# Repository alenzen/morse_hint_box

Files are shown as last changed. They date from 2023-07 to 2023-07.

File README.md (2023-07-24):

Morse Code Hint Box
===================

A little puzzle game as a weeding gift to our dear friends.

Two Arduino UNOs are involved: the first is the hint box, it has an e-paper
display to show hints and waits for a code word to be sent as Morse code over a
wire. It has a three pin connector. The second is what our friends get to
program themselves. They need to hook it up to the box and Morse the
code word. As code, by a button, however.

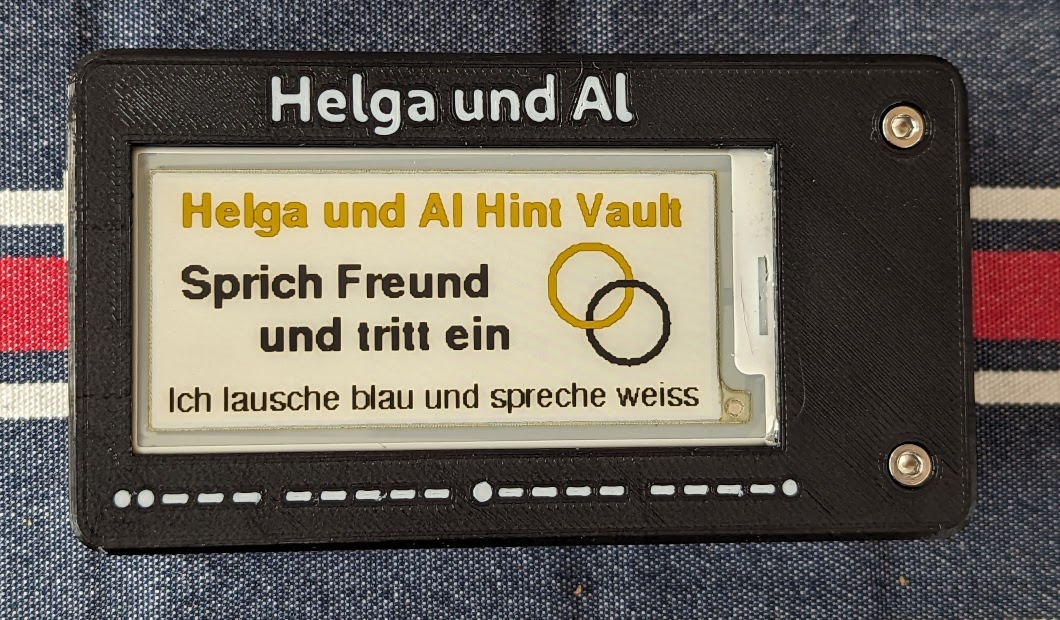
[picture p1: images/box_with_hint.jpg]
Hint box after powering up


Creative Commons BY-NC-SA

Build Instructions
------------------

Material required: Arduino Uno, cables, 2.54 mm 3-pin header (1x female, 1x
male), 2.54 mm 4-pin Dupont connector (1x male, 1x female)
[set with tool](https://www.amazon.de/gp/product/B07QX51F3B/),
[Waveshare E-Paper shield](https://www.waveshare.com/wiki/E-Paper_Shield),
[Waveshare 2.9inch 3-color e-inkdisplay](https://www.waveshare.com/wiki/2.9inch_e-Paper_Module_(C)),
a bit of filament and a 3D printer.

1. Print the housing, update the strings in the slicer files (.3cf). In the
   example, the lower part is a number in Morse code. You need to print with
   supports for the lid, requires a bit of work but are generally easy to
   remove.
2. Mount E-Paper shield to Arduino
3. Solder 3 wires to the shield: 1 to ground, 1 to D3 (this one is important and
   must be on this pin to support hardware interrupts), and 1 to SDA (that one
   doesn't matter too much, you can use another pin as long it's one supporting
   digital output and not colliding with the pins used by the shield). I have
   used solid core cables for this part.
4. Solder the cables to the 2.54 mm male pin header
5. Mount pin header into the holder in the box.
6. Create a connection with three cables, I have used blue (receive), white
   (send), and black (ground). The order on the Dupont header matters:
   ground, empty, white, blue. The empty one is to spare data pin 13, such that
   the builtin LED can be used. This way, I would plug the connector to the
   secondary Arduino into GND, empty on pin 13, and pins 12 and 11.
7. Mount e-paper display into lid, slide cable through hole and display slightly
   into overhang, move fully down and then slide slightly back into far side
   for full hold.
8. Screw lid on body
9. Modify [morse_hint_box.ino](morse_hint_box/morse_hint_box.ino) to your liking
   and upload to box Arduino.
10. Play with [simple_receiver.ino](simple_receiver/simple_receiver.ino) and
    [solution_full_alphabet.ino](solution_full_alphabet/solution_full_alphabet.ino)
    to send and receive.

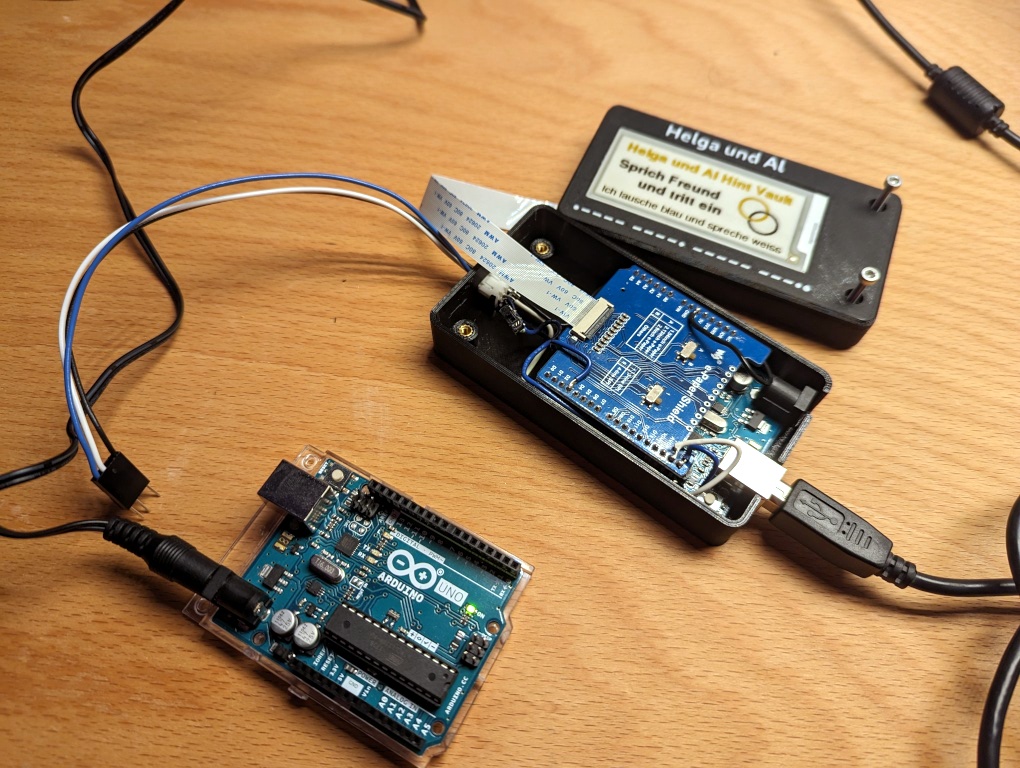
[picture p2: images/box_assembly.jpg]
Hint box assembly


Ignore the switch in the image. I used it to enable switching the input from pin3
to SCL. This way I could also have used I²C for the challenge instead of digital
pins.

Conducting
----------

We did this in-person and the goal of the puzzle is to get another hint to
which person to go next. But obviously this could be tweaked to reveal
anything.

I asked our friends to install the Arduino IDE. They would get the second
Arduino to run their solution. They figured out that it was Morse code rather
quickly. I flashed the second Arduino with [ask_help.ino](ask_help/ask_help.ino).
Then, after plugging in, the Morse parameters and alphabet screens would come up.
The parameters are crucial to be able to properly send.

Then they were equipped with everything necessary and Morse from the bsd-games
package made it (almost too) easy to create the sequence. They initially sent
what was written on the box. Nice try, I nudged them towards the little puzzle
on the start screen. Then it was a matter of typing speed. Overall solving this
took maybe an hour. It was somewhat similar to
[solution_simple.ino](solution_simple/solution_simple.ino).

I'd be really curious for modifications that require sending and receiving. But
the receiver code is a bit more involved and requires some actual programming
(cf. [simple_receiver.ino](simple_receiver/simple_receiver.ino)). I would
consider this in particular if the one supposed to hack the box could do this on
their own time. For the in-person challenge the Morse reading code may be a
little bit too much.

Have fun!

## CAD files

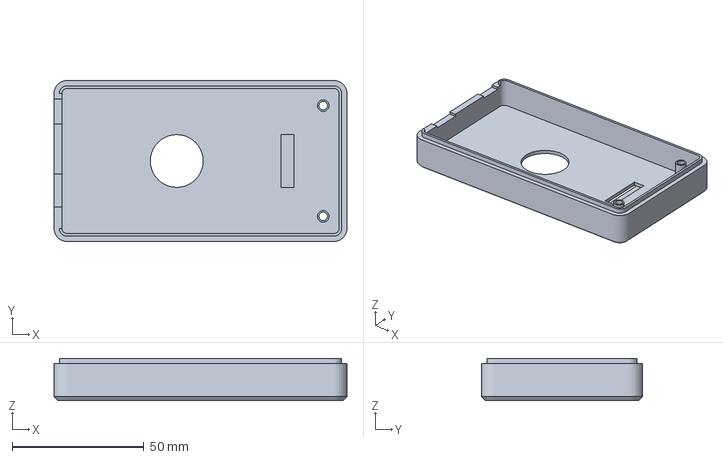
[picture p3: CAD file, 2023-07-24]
models/Arduino_Uno_Case_With_Epaper_Lid_v2.3mf
111.0 x 61.0 x 16.0 mm

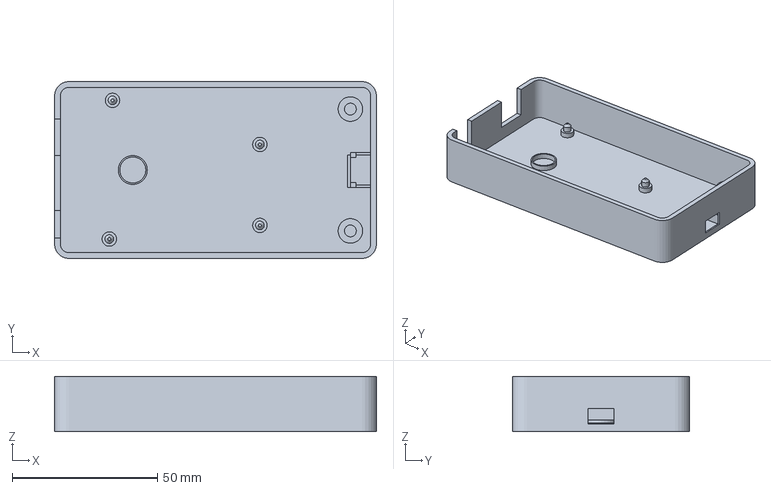
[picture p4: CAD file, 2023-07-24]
models/Arduino_Uno_Case_With_Epaper_Body_v2.3mf
111.0 x 61.0 x 19.0 mm

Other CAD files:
models/Arduino_Uno_Case_With_Epaper_Body_v2.stl
models/Arduino_Uno_Case_With_Epaper_Lid_v2.stl

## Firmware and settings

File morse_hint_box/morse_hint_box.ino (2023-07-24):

// Morse Code Hint Box
// Copyright (C) 2023 Tim Niemueller

// Required libraries: GxEPD2, TimerOne

#include <GxEPD2_BW.h>
#include <GxEPD2_3C.h>
#include <GxEPD2_7C.h>
#include <Fonts/FreeSansBold12pt7b.h>
#include <Fonts/FreeSans9pt7b.h>
#include <TimerOne.h>

// select the display class and display driver class in the following file (new style):
#include "GxEPD2_display_selection_new_style.h"

#define DEG2RAD 0.0174532925

// Morse pins
#define PIN_IN 3
#define PIN_OUT SDA

#define MORSE_CODE_LENGTH 36
const char *morse_code[MORSE_CODE_LENGTH] = {
  // a-z
  ".-", "-...", "-.-.", "-..", ".", "..-.", "--.", "....", "..", ".---", "-.-", ".-..", "--",
  "-.", "---", ".--.", "--.-", ".-.", "...", "-", "..-", "...-", ".--", "-..-", "-.--", "--..",
  // 0-9
  "-----", ".----", "..---", "...--", "....-", ".....", "-....", "--...", "---..", "----."
};

// We accept German and Elvish, no Klingon this time :-)
#define SECRET_WORD_1 "freund"
#define SECRET_WORD_2 "mellon"
#define HELP_WORD "help"

#define INSTRUCTION_SWITCH_INTERVAL 10000

#define TIME_UNIT    (250)
#define DOT          TIME_UNIT
#define DASH         (3*TIME_UNIT)
#define SYMBOL_SPACE TIME_UNIT

#define SEND_LETTER_SPACE  (3*TIME_UNIT - SYMBOL_SPACE)
#define RECV_LETTER_SPACE  (3*TIME_UNIT)
#define SEND_WORD_SPACE    (7 * TIME_UNIT - SEND_LETTER_SPACE)
#define RECV_WORD_SPACE    (7 * TIME_UNIT)
#define RECV_ERASE_TIMEOUT (20 * TIME_UNIT)

#define LETTER_BUFFER_SIZE  8
#define WORD_BUFFER_SIZE   10

#define SYMBOL_DOT  '.'
#define SYMBOL_DASH '-'

// buffer to read strings from progmem
// We need progmem to store strings to reduce SRAM usage.
char progmem_buffer[40];

// Variables for RECEIVING
volatile unsigned long last_low_millis = 0;
volatile unsigned long last_high_millis = 0;
volatile char word_buffer[WORD_BUFFER_SIZE];
volatile char letter_buffer[LETTER_BUFFER_SIZE];
volatile byte letter_buffer_index = 0;
volatile byte word_buffer_index = 0;
volatile bool word_complete = false;

typedef enum {
  INIT,
  START,
  INSTRUCTIONS,
  HINT
} State;
volatile State last_state = INIT;
volatile State state = START;

// Parse buffer of symbols for a single letter
void parse_letter_buffer() {
  for (int i = 0; i < MORSE_CODE_LENGTH; ++i) {
    if (strcmp(morse_code[i], letter_buffer) == 0) {
      if (i < ('z' - 'a')) {
        word_buffer[word_buffer_index] = 'a' + i;
      } else {
        word_buffer[word_buffer_index] = i - ('z' - 'a' + 1) + '0';
      }
      word_buffer_index += 1;
      if (word_buffer_index >= WORD_BUFFER_SIZE) {
        word_complete = true;
      }
    }
  }
  for (int i = 0; i < LETTER_BUFFER_SIZE; ++i) letter_buffer[i] = 0;
  letter_buffer_index = 0;
}

// Remove all data from inflow buffers
void flush_buffers() {
  for (int i = 0; i < LETTER_BUFFER_SIZE; ++i) letter_buffer[i] = 0;
  for (int i = 0; i < WORD_BUFFER_SIZE; ++i) word_buffer[i] = 0;
  letter_buffer_index = 0;
  word_buffer_index = 0;
  word_complete = false;
}

// Interrupt function to read morse code based on signal changes.
void read_morse() {
  if (digitalRead(PIN_IN) == HIGH) {
    digitalWrite(LED_BUILTIN, LOW);
    last_high_millis = millis();
    if ((millis() - last_low_millis) <= 1.1 * DOT) {
      //Serial.println(SYMBOL_DOT);
      letter_buffer[letter_buffer_index] = SYMBOL_DOT;
      letter_buffer_index += 1;
    } else if ((millis() - last_low_millis) <= 1.1 * DASH) {
      //Serial.println(SYMBOL_DASH);
      letter_buffer[letter_buffer_index] = SYMBOL_DASH;
      letter_buffer_index += 1;
    } /* else {
      if (state != HINT) {
        state = INSTRUCTIONS;
      }
    } */
    if (letter_buffer_index >= LETTER_BUFFER_SIZE) {
      // overflow, flush letter buffer
      for (int i = 0; i < LETTER_BUFFER_SIZE; ++i) letter_buffer[i] = 0;
      letter_buffer_index = 0;
    }
  } else {
    digitalWrite(LED_BUILTIN, HIGH);
    last_low_millis = millis();
    unsigned int time_since_high = millis() - last_high_millis;
    if (time_since_high > 0.9 * RECV_LETTER_SPACE) {
      parse_letter_buffer();
    }
    if (time_since_high > 0.9 * RECV_WORD_SPACE && word_buffer_index > 0) {
      word_complete = true;
    }
    if (time_since_high > RECV_ERASE_TIMEOUT) {
      flush_buffers();
    }
  }
}

void write_for(int time_ms) {
  digitalWrite(PIN_OUT, LOW);
  //digitalWrite(LED_BUILTIN, HIGH);
  delay(time_ms);
  digitalWrite(PIN_OUT, HIGH);
  //digitalWrite(LED_BUILTIN, LOW);
  delay(SYMBOL_SPACE);
}

void write_morse(char* message) {
  Serial.print("Sending: ");
  Serial.println(message);
  for (int i = 0; i < strlen(message); ++i) {
    int letter = tolower(message[i]);
    if (letter == ' ') {
      delay(SEND_WORD_SPACE);
    } else if (letter >= 'a' && letter <= 'z') {
      const char* morse_letter = morse_code[letter - 'a'];
      for (int j = 0; j < strlen(morse_letter); ++j) {
        write_for((morse_letter[j] == '.') ? DOT : DASH);
      }
    } else if (letter >= '0' && letter <= '9') {
      const char* morse_letter = morse_code[letter + 26 - '0'];
      for (int j = 0; j < strlen(morse_letter); ++j) {
        write_for((morse_letter[j] == '.') ? DOT : DASH);
      }
    }
    delay(SEND_LETTER_SPACE);
  }
}


const char screenStartTitle[] PROGMEM = "Helga und Al Hint Vault";
const char screenStartRiddle1[] PROGMEM = "Sprich Freund";
const char screenStartRiddle2[] PROGMEM = "und tritt ein";
const char screenStartInstructions[] PROGMEM = "Ich lausche blau und spreche weiss";

void screenStart()
{
  display.setRotation(1);
  display.setFullWindow();
  display.firstPage();
  do
  {
    display.fillScreen(GxEPD_WHITE);
    display.setFont(&FreeSansBold12pt7b);
    display.setTextColor(GxEPD_YELLOW);
    int16_t tbx, tby; uint16_t tbw, tbh;
    strcpy_P(progmem_buffer, screenStartTitle);
    display.getTextBounds(progmem_buffer, 0, 0, &tbx, &tby, &tbw, &tbh);
    // center the bounding box by transposition of the origin:
    uint16_t top_x = ((display.width() - tbw) / 2) - tbx;
    uint16_t y = tbh+2;//((display.height() - tbh) / 2) - tby;
    display.setCursor(top_x, y);
    display.print(progmem_buffer);

    uint16_t radius = 20;
    fillArc2(display.width() - 3.25*radius, tbh+1.75*radius, 0, 120, radius+3, radius+3, 3, GxEPD_YELLOW);
    fillArc2(display.width() - 2.25*radius, tbh+2.75*radius, 0, 120, radius+3, radius+3, 3, GxEPD_BLACK);
    fillArc2(display.width() - 3.25*radius, tbh+1.75*radius, 170, 6, radius+3, radius+3, 3, GxEPD_YELLOW);

    display.setTextColor(GxEPD_BLACK);
    strcpy_P(progmem_buffer, screenStartRiddle1);
    display.getTextBounds(progmem_buffer, 0, 0, &tbx, &tby, &tbw, &tbh);
    uint8_t x = top_x;
    y = tbh+2*radius;
    display.setCursor(x, y);
    display.print(progmem_buffer);

    strcpy_P(progmem_buffer, screenStartRiddle2);
    display.getTextBounds(progmem_buffer, top_x, y, &tbx, &tby, &tbw, &tbh);
    x = top_x + 40;
    y = y + tbh + 10;
    display.setCursor(x, y);
    display.print(progmem_buffer);

    display.setTextColor(GxEPD_BLACK);
    display.setFont(&FreeSans9pt7b);
    strcpy_P(progmem_buffer, screenStartInstructions);
    display.getTextBounds(progmem_buffer, 0, 0, &tbx, &tby, &tbw, &tbh);
    x = ((display.width() - tbw) / 2) - tbx;
    y = (display.height() - tbh - 2) - tby;
    display.setCursor(x, y);
    display.print(progmem_buffer);

  } while (display.nextPage());
}

void displayPrintMorseLetter(uint16_t x, uint16_t y, const char* letter) {
  for (int i = 0; i < strlen(letter); ++i) {
    if (letter[i] == SYMBOL_DOT) {
      //fillArc2(x + i * 8, y - 4, 0, 120, 2, 2, 2, GxEPD_YELLOW);
      display.fillRect(x + i * 8 + 2, y - 10 - 1, 2, 2, GxEPD_YELLOW);
    } else {
      display.fillRect(x + i * 8, y - 10 - 1, 6, 2, GxEPD_YELLOW);
    }
  }
}

void screenMorseAlphabet()
{
  display.setRotation(1);
  display.setFullWindow();
  display.firstPage();
  do
  {
    display.fillScreen(GxEPD_WHITE);
    display.setFont(&FreeSans9pt7b);
    for (int row = 0; row < 9; ++row) {
      for (int col = 0; col < 4; ++col) {
        byte letter_index = row * 4 + col;
        char letter_buffer[] = {
          (letter_index < ('z' - 'a' + 1)) ? ('a' + letter_index) : ('0' + letter_index - ('z' - 'a' + 1)),
          0
        };
        int16_t tbx, tby; uint16_t tbw, tbh;
        display.getTextBounds(letter_buffer, 0, 0, &tbx, &tby, &tbw, &tbh);
        // center the bounding box by transposition of the origin:
        uint16_t x = (col * 74) - tbx + 10;
        uint16_t y = (row * 14) - tby + 1;
        display.setCursor(x, y);
        display.setTextColor(GxEPD_BLACK);
        display.print(letter_buffer);

        display.setCursor(x+20, y);
        display.setTextColor(GxEPD_YELLOW);
        displayPrintMorseLetter(x+20, y + 7, morse_code[letter_index]);
      }
    }
  } while (display.nextPage());
}

const char screenMorseParametersTitle[] PROGMEM = "Morse Parameters";
const char screenMorseSignal[] PROGMEM = "Signal on LOW";
const char screenMorseSymbolLengthDesc[] PROGMEM = "Symbol time:";
const char screenMorseSymbolLength1[] PROGMEM = "DOT 250 ms";
const char screenMorseSymbolLength2[] PROGMEM = "DASH 750 ms";
const char screenMorsePauseLengthDesc[] PROGMEM = "Pause time: ";
const char screenMorsePauseLength1[] PROGMEM = "Symbol 250 ms";
const char screenMorsePauseLength2[] PROGMEM = "Letter 750 ms";
const char screenMorsePauseLength3[] PROGMEM = "Word 1750ms";

void screenMorseParameters()
{
  display.setRotation(1);
  display.setFullWindow();
  display.firstPage();
  do
  {
    display.fillScreen(GxEPD_WHITE);
    display.setFont(&FreeSansBold12pt7b);
    display.setTextColor(GxEPD_YELLOW);
    int16_t tbx, tby; uint16_t tbw, tbh;
    strcpy_P(progmem_buffer, screenMorseParametersTitle);
    display.getTextBounds(progmem_buffer, 0, 0, &tbx, &tby, &tbw, &tbh);
    // center the bounding box by transposition of the origin:
    uint16_t x = ((display.width() - tbw) / 2) - tbx;
    uint16_t y = tbh+2;
    display.setCursor(x, y);
    display.print(progmem_buffer);

    display.setFont(&FreeSans9pt7b);
    display.setTextColor(GxEPD_BLACK);

    x = 16;
    y = 40;
    strcpy_P(progmem_buffer, screenMorseSignal);
    display.setCursor(x, y);
    display.print(progmem_buffer);

    y += 16;
    strcpy_P(progmem_buffer, screenMorseSymbolLengthDesc);
    display.getTextBounds(progmem_buffer, 0, 0, &tbx, &tby, &tbw, &tbh);
    display.setCursor(x, y);
    display.print(progmem_buffer);
    strcpy_P(progmem_buffer, screenMorseSymbolLength1);
    display.setCursor(x + tbw + 4, y);
    display.print(progmem_buffer);
    strcpy_P(progmem_buffer, screenMorseSymbolLength2);
    y += 16;
    display.setCursor(x + tbw + 4, y);
    display.print(progmem_buffer);

    strcpy_P(progmem_buffer, screenMorsePauseLengthDesc);
    y += 18;
    display.setCursor(x, y);
    display.print(progmem_buffer);
    strcpy_P(progmem_buffer, screenMorsePauseLength1);
    display.setCursor(x + tbw + 4, y);
    display.print(progmem_buffer);
    strcpy_P(progmem_buffer, screenMorsePauseLength2);
    y += 16;
    display.setCursor(x + tbw + 4, y);
    display.print(progmem_buffer);
    strcpy_P(progmem_buffer, screenMorsePauseLength3);
    y += 16;
    display.setCursor(x + tbw + 4, y);
    display.print(progmem_buffer);

  } while (display.nextPage());
}

const char screenHintTitle[] PROGMEM = "Geschafft!";
const char screenHintRiddle1[] PROGMEM = "Und nun auf";
const char screenHintRiddle2[] PROGMEM = "zum lieben...";
const char screenHintGroup1[] PROGMEM = "Tob -> Buck -> Tim -> ...";
const char screenHintDots[] PROGMEM = "...";
const char screenHintGroup2[] PROGMEM = "Appel";

void screenHint1()
{
  display.setRotation(1);
  display.setFullWindow();
  display.firstPage();
  do
  {
    display.fillScreen(GxEPD_WHITE);
    display.setFont(&FreeSansBold12pt7b);
    display.setTextColor(GxEPD_YELLOW);
    int16_t tbx, tby; uint16_t tbw, tbh;
    strcpy_P(progmem_buffer, screenHintTitle);
    display.getTextBounds(progmem_buffer, 0, 0, &tbx, &tby, &tbw, &tbh);
    // center the bounding box by transposition of the origin:
    uint16_t top_x = ((display.width() - tbw) / 2) - tbx;
    uint16_t y = tbh+2;//((display.height() - tbh) / 2) - tby;
    display.setCursor(top_x, y);
    display.print(progmem_buffer);

    uint16_t radius = 20;
    fillArc2(display.width() - 3*radius, tbh+2.75*radius, 0, 120, radius+3, radius+3, 3, GxEPD_YELLOW);
    fillArc2(display.width() - 2.75*radius, tbh+3*radius, 0, 120, 5, 5, 5, GxEPD_YELLOW);
    fillArc2(display.width() - 2.25*radius, tbh+2*radius, 270, 30, 20, 15, 2, GxEPD_BLACK);

    display.setTextColor(GxEPD_BLACK);
    strcpy_P(progmem_buffer, screenHintRiddle1);
    display.getTextBounds(progmem_buffer, 0, 0, &tbx, &tby, &tbw, &tbh);
    y = tbh+2*radius;
    display.setCursor(20, y);
    display.print(progmem_buffer);

    strcpy_P(progmem_buffer, screenHintRiddle2);
    display.getTextBounds(progmem_buffer, top_x, y, &tbx, &tby, &tbw, &tbh);
    y = y + tbh + 10;
    display.setCursor(20 + 40, y);
    display.print(progmem_buffer);

    display.setTextColor(GxEPD_BLACK);
    display.setFont(&FreeSans9pt7b);
    strcpy_P(progmem_buffer, screenHintGroup1);
    display.getTextBounds(progmem_buffer, 0, 0, &tbx, &tby, &tbw, &tbh);
    int16_t tbx2, tby2; uint16_t tbw2, tbh2;
    strcpy_P(progmem_buffer, screenHintGroup2);
    display.getTextBounds(progmem_buffer, 0, 0, &tbx2, &tby2, &tbw2, &tbh2);
    uint16_t x = ((display.width() - tbw - tbw2) / 2) - tbx;
    y = (display.height() - tbh - 2) - tby - 3;
    display.setCursor(x, y);
    strcpy_P(progmem_buffer, screenHintGroup1);
    display.print(progmem_buffer);

  } while (display.nextPage());
}

void screenHint2()
{
  display.setRotation(1);
  display.firstPage();
  do
  {
    display.fillScreen(GxEPD_WHITE);

    display.setTextColor(GxEPD_BLACK);
    display.setFont(&FreeSans9pt7b);
    int16_t tbx, tby; uint16_t tbw, tbh;
    strcpy_P(progmem_buffer, screenHintGroup1);
    display.getTextBounds(progmem_buffer, 0, 0, &tbx, &tby, &tbw, &tbh);
    int16_t tbx2, tby2; uint16_t tbw2, tbh2;
    strcpy_P(progmem_buffer, screenHintGroup2);
    display.getTextBounds(progmem_buffer, 0, 0, &tbx2, &tby2, &tbw2, &tbh2);
    int16_t tbx3, tby3; uint16_t tbw3, tbh3;
    strcpy_P(progmem_buffer, screenHintDots);
    display.getTextBounds(progmem_buffer, 0, 0, &tbx3, &tby3, &tbw3, &tbh3);


    uint16_t x = ((display.width() - tbw - tbw2) / 2) + tbw - tbw3 - tbx;
    uint16_t y = (display.height() - tbh - 2) - tby - 3;

    display.setPartialWindow(x, y - tbh2, tbw2, tbh2);
    display.setCursor(x, y);
    strcpy_P(progmem_buffer, screenHintGroup2);
    display.print(progmem_buffer);

  } while (display.nextPage());
}

// #########################################################################
// Draw a circular or elliptical arc with a defined thickness
// #########################################################################

// Various places on the web, don't know the actual origin
// I took this from https://forum.arduino.cc/t/adafruit_gfx-fillarc/397741/7

// x,y == coords of centre of arc
// start_angle = 0 - 359
// seg_count = number of 3 degree segments to draw (120 => 360 degree arc)
// rx = x axis radius
// yx = y axis radius
// w  = width (thickness) of arc in pixels
// colour = 16 bit colour value
// Note if rx and ry are the same then an arc of a circle is drawn

int fillArc2(int x, int y, int start_angle, int seg_count, int rx, int ry, int w, unsigned int colour)
{

  byte seg = 3; // Segments are 3 degrees wide = 120 segments for 360 degrees
  byte inc = 3; // Draw segments every 3 degrees, increase to 6 for segmented ring

    // Calculate first pair of coordinates for segment start
    float sx = cos((start_angle - 90) * DEG2RAD);
    float sy = sin((start_angle - 90) * DEG2RAD);
    uint16_t x0 = sx * (rx - w) + x;
    uint16_t y0 = sy * (ry - w) + y;
    uint16_t x1 = sx * rx + x;
    uint16_t y1 = sy * ry + y;

  // Draw colour blocks every inc degrees
  for (int i = start_angle; i < start_angle + seg * seg_count; i += inc) {

    // Calculate pair of coordinates for segment end
    float sx2 = cos((i + seg - 90) * DEG2RAD);
    float sy2 = sin((i + seg - 90) * DEG2RAD);
    int x2 = sx2 * (rx - w) + x;
    int y2 = sy2 * (ry - w) + y;
    int x3 = sx2 * rx + x;
    int y3 = sy2 * ry + y;

    display.fillTriangle(x0, y0, x1, y1, x2, y2, colour);
    display.fillTriangle(x1, y1, x2, y2, x3, y3, colour);

    // Copy segment end to sgement start for next segment
    x0 = x2;
    y0 = y2;
    x1 = x3;
    y1 = y3;
  }
}

void process_read_buffer() {
  noInterrupts();
  if (millis() - last_high_millis > RECV_WORD_SPACE &&
      (word_buffer_index > 0 || letter_buffer_index > 0)) {
    parse_letter_buffer();
    word_complete = true;
  }
  if (word_complete) {
    if (word_buffer_index > 0) {
      Serial.print("Received word: ");
      Serial.println((const char*)word_buffer);
      if (strcmp(word_buffer, SECRET_WORD_1) == 0 ||
          strcmp(word_buffer, SECRET_WORD_2) == 0) {
        state = HINT;
      }
      if (strcmp(word_buffer, HELP_WORD) == 0 && last_state != INSTRUCTIONS) {
        state = INSTRUCTIONS;
      }
    }
    word_complete = false;
    flush_buffers();
  }
  interrupts();
}

void setup()
{
  Serial.begin(115200);
  display.init(115200, true, 2, false); // USE THIS for Waveshare boards with "clever" reset circuit, 2ms reset pulse

  pinMode(PIN_IN, INPUT_PULLUP);
  pinMode(PIN_OUT, OUTPUT);
  pinMode(LED_BUILTIN, OUTPUT);

	// Setup interrupt for morse reading
  attachInterrupt(digitalPinToInterrupt(PIN_IN), read_morse, CHANGE);

	// Initial signal HIGH and turn LED off
  digitalWrite(PIN_OUT, HIGH);
  digitalWrite(LED_BUILTIN, LOW);

	// Initialize timer for processing read buffer
  Timer1.initialize(10000);
  Timer1.attachInterrupt(process_read_buffer);

  Serial.println("Start");
}

unsigned long last_write_millis = 0;
void loop() {
  if (state != last_state) {
    last_state = state;
    switch (state) {
      case START:
        Serial.println("Switching state to START");
        screenStart();
        break;

      case INSTRUCTIONS:
        Serial.println("Switching state to INSTRUCTIONS");
        screenMorseParameters();
        delay(INSTRUCTION_SWITCH_INTERVAL);
        screenMorseAlphabet();
        delay(INSTRUCTION_SWITCH_INTERVAL);
        state = START;
        break;

      case HINT:
        Serial.println("Switching state to HINT");
        screenHint1();
        delay(15000);
        screenHint2();
        break;

    }
    display.hibernate();
  }
  if (millis() - last_write_millis > 2500) {
    write_morse("hallo");
    last_write_millis = millis();
  }
  delay(10);
};

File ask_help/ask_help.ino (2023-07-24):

#define PIN_OUT 11

// Times defined in milliseconds
#define TIME_UNIT    (250)
#define DOT          TIME_UNIT
#define DASH         (3*TIME_UNIT)
#define SYMBOL_SPACE TIME_UNIT
#define LETTER_SPACE (3 * TIME_UNIT - SYMBOL_SPACE)
#define WORD_SPACE   (7 * TIME_UNIT - LETTER_SPACE)

void setup() {
  // Serial setup (optional, can be used for debugging output)
  Serial.begin(115200);

  // input is with pullup resistor, therefore "LOW" on that pin is signal
  pinMode(PIN_OUT, OUTPUT);
  // use builtin LED to visualize what is sent
  pinMode(LED_BUILTIN, OUTPUT);

  // signal HIGH and turn off LED initially
  digitalWrite(PIN_OUT, HIGH);
  digitalWrite(LED_BUILTIN, LOW);
}

// Writes a single symbol, either DOT or DASH
void write_symbol(int symbol_time_ms) {
  digitalWrite(PIN_OUT, LOW);
  digitalWrite(LED_BUILTIN, HIGH);
  delay(symbol_time_ms);
  digitalWrite(PIN_OUT, HIGH);
  digitalWrite(LED_BUILTIN, LOW);
  delay(SYMBOL_SPACE);
}

void loop() {
  // Send "help" over the wire
  // Morse code alphabet at https://en.wikipedia.org/wiki/Morse_code

  // h: ....
  write_symbol(DOT);
  write_symbol(DOT);
  write_symbol(DOT);
  write_symbol(DOT);
  delay(LETTER_SPACE);

  // e: .
  write_symbol(DOT);
  delay(LETTER_SPACE);

  // l: .-..
  write_symbol(DOT);
  write_symbol(DASH);
  write_symbol(DOT);
  write_symbol(DOT);
  delay(LETTER_SPACE);

  // p: .--.
  write_symbol(DOT);
  write_symbol(DASH);
  write_symbol(DASH);
  write_symbol(DOT);
  delay(LETTER_SPACE);

  delay(WORD_SPACE);
}

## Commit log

2023-07-24 First step for simple solution, PIN configuration
2023-07-24 simple solution pin configuration
2023-07-24 simple receiver that prints words received as morse code
2023-07-24 STL and Prusa slicer models for the case
    Ready to be 3D printed. Text only in Prusa Slicer files.
    [Arduino_Uno_Case_With_Epaper_Body_v2.3mf, Arduino_Uno_Case_With_Epaper_Body_v2.stl, Arduino_Uno_Case_With_Epaper_Lid_v2.3mf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]
